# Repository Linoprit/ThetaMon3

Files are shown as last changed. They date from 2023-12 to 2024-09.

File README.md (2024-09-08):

# ThetaMon3

ThetaMon3 is based on an ESP32 controller, which reads a bunch of sensors and sends the results to a MQTT-Broker, like Mosquitto. I use three probes, together with my Home Assistant installation to control the temperature in remote buildings.

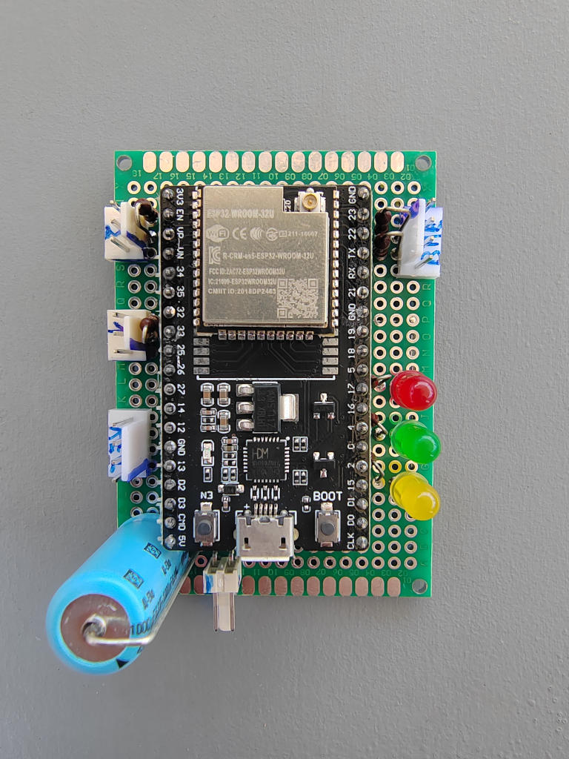
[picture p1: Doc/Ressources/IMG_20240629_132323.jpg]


## Features Overview

- Reads DS18B20 sensor array, connected to two channels. In the current configuration, it can read up to five sensors per channel. If you need more, simply increase DS18B20_MAX_DEVICES in Config.h.
- It also reads BME280 values, temp, hummidity and pressure.
- Currently, every channel needs at least one sensor. So a minimum configuration is two DS18B20 sensors and one BME280. 
- Based on a look-up table, placed as file image on the controller, two relays are switched, depending on the given thresholds. Every device works independently.
- Measurements are taken every minute and the average of these measurements are sent to an Mqtt broker every five minutes.
- There is a command-line-interface, you could connect to with a terminal programm, like GTK-Term. So you can have insight, what is going on in your setup and you can change several settings with it.
- Also, there are Mqtt-channels for remote accessing the device, or read loggings.

Why two OneWire-channels?<br>
I simply had the problem that in the workshop the location of the probe was in the middle of the sensor chain. Unfortunately, it was not possible to place it at one end or the other of the sensor chain.

## What's it all about? 

To understand what ThetaMon does and what it is meant for, we take a look at where the idea comes from.

My wife owns really a lot of pot-plants. These must be kept in a warmer place during the winter time, so we bring them into the garages. Unfortunately, on some days the outside temperatures could drop so low, that even in the garage the plants will die. Of course you use an electric heater, but the control of such devices is not particularly precise.
So the idea came up to build a system, that measures at different places in the room, to bring more insight how the heat is distributed and which places are save. Above that, to provide a finer regulation of the heating.

I put together the first version of ThetaMon, based on STM32F103 controllers, it consisted of two satellites and a base-station. The communication was done with NRF24 radios, which are long range capable (more or less...). The base-station was connected to an orange-pi which ran an apache webserver installation and hosted a page to show the graphs of all sensors for the last 24 hours. One very crucial point was, that the satellites work independently. If the connection to the base broke, they must have benn capable to do the regulation. This means, that every node in the system has to keep a table with all relevant temperature-thresholds.

This system ran fine for some years, but I wanted more flexibility and insight, if things went wrong. Sometimes temperature sensors failed, due to connector problems, or the NRF24 modules failed.
ThetaMon2 took a very long time to develop, and it became very complex. For example I needed an EEPROM with some kind of file-system to store the sensor tables. The html-generation was done by own code on the used Banana-Pi. Finaly it worked and it was used for one year.

In winter 2023 I took the time to try, if ESP32 with external antenna could keep a stable connection to the Wlan. And yes, it did! Also I looked for some different possibility to do the development and found, that PlatformIO is so much powerfull. Then, a colleague showed me what he does with home automation and I came up to use Home Assistant as dashboard solution.
ThetaMon3 took only a half year of development, not only because large parts of code from TM2 have been overtaken, it turned out that PlatformIO absolutely speeds up things.

## Getting started

Refer to: [SettingUpThetaMonProbe](https://github.com/Linoprit/ThetaMon3/blob/main/Doc/SettingUpThetaMonProbe.pdf).<br>
You need a working Visual Studio Code, together with PlatformIO. 

For a complete command-reference see [CommandLineReference](https://github.com/Linoprit/ThetaMon3/blob/main/Doc/CommandLineReference.pdf).

## Integrating to Home Assistant

The probes data is transmitted via mqtt, so you could integrate it whereever you want.
Because I use HA, I describe the integration for it. 

The name of your location (spot), where the probe is placed is defined in „MqttConfig.txt“, that resides on your ESP. Every sensor has a shortname, defined in „ID_Table_U64.txt“. These two names result in a mqtt publishing, in the form \<Location>/sens/\<Sensor-Shortname>. Your Home Automation system has to subscribe every sensor. The sensor data is transmitted in Json-format, i.e. "{"HUMID":51.21}"

Your Mosquitto installation and setup should have been done in the last step. You could use Home Assistants Mosquitto plugin.<br>
Go to the file /homeassistant/configuration.yaml, use the text-editor-plugin. 
Create a new section 
```
mqtt:
    sensor:
```
Then for every sensor enter a block like this:
```
    - name: "<Location> <Sensor-Shortname>"
      unique_id: <Location><Sensor-Shortname>
      state_class: "measurement"
      state_topic: "<Location>/sens/<Sensor-Shortname>"
      unit_of_measurement: "°C"
      expire_after: 480
      value_template: "{{ value_json.TEMP }}"
```
### Unit and value_template for other sensors:

Pressure:
```
      unit_of_measurement: "hPa"
      value_template: "{{ value_json.PRESS }}"
```

Hummidity:
```
      unit_of_measurement: "%"
      value_template: "{{ value_json.HUMID }}"
```

Relay:
```
      unit_of_measurement: "0/1"
      value_template: "{{ value_json.RELAY }}"
```

Example configuration:
```
# -- ESP32 Sensors --
mqtt:
    sensor:    
    - name: "Lager Temperatur"
      unique_id: LagerTmp
      state_class: "measurement"
      state_topic: "Lager/sens/LagerTmp"
      unit_of_measurement: "°C"
      expire_after: 480
      value_template: "{{ value_json.TEMP }}"
    - name: "Lager Luftdruck"
      unique_id: LagerPrs
      state_class: "measurement"
      state_topic: "Lager/sens/LagerPrs"
      unit_of_measurement: "hPa"
      expire_after: 480
      value_template: "{{ value_json.PRESS }}"
    - name: "Lager Luftfeuchte"
      unique_id: LagerHum
      state_topic: "Lager/sens/LagerHum"
      state_class: "measurement"
      unit_of_measurement: "%"
      expire_after: 480
      value_template: "{{ value_json.HUMID }}"
    - name: "Lager  Relay 1"
      unique_id: LagerRl1
      state_topic: "Lager/sens/LagerRl1"
      state_class: "measurement"
      unit_of_measurement: "0/1"
      expire_after: 480
      value_template: "{{ value_json.RELAY }}"
    - name: "Lager  Relay 2"
      unique_id: LagerRl2
      state_topic: "Lager/sens/LagerRl2"
      state_class: "measurement"
      unit_of_measurement: "0/1"
      expire_after: 480
      value_template: "{{ value_json.RELAY }}"
```

## Listen to the probes logging
Every probe publishes it's logging. It can be monitored with
```
mosquitto_sub -u mosquitto -P public -h <server-ip> -t <Location>/log
```

## Commands from remote
Via Mosquitto, commands can be sent to your probe with
```
mosquitto_pub -t '<Location>/cmd' -m '<Command>'
```
Best practise is to have a second terminal open with a running log-subscription.

## ToDo
- Explain how TM3 works. Measurement_Pivot, CommLine-Interface...?
- Discussion, if digital input / output channels are needed.
- Make Mqtt-credentials changeable, append them to MqttConfig.
- Move all Mqtt related commands in a structure and apply the "hasChanged" mechanism, used in sensor-configuration.

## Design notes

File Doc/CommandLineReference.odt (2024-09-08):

# ThetaMon3 Command-Line Reference

Refer to file “Interpreter.cpp”

Connect your computer to the ESP32 via USB-cable. Start a terminal-application like Gtk-Term, set the right port, i.e. /dev/ttyUSB0 or /dev/ttyACM0. Turn local echo off.

You could also use Visual Studio Codes Serial Monitor. Push the “Toggle Terminal Mode” button for enabling typing in commands.

Remember to shut down the terminal, or disconnect it, if you want to flash the ESP, or write the file-sytem image.

String arguments must be in double quotes (i.e. “Workshop”), Floats have to be written with a dot as decimal separator.

Like in Unix-terminals, you could access the history with arrow up / down.

setSensId <Sensor-Hash> <min> <max> <sensor-type> <relay-channel> “<shortname>”

float <min>:

Lower threshold, where the relay-channel is switched on.
float <max>:

Upper threshold, where the relay-channel is switched off,
int <sensor-type>:
0 – Temperature
1 – Humidity
2 – Pressure
3 – Relay (We treat Relays as sensor, to read their states)
int <relay-channel>:
0 – No channel. This sensor doesn’t switch anything.
1 – Channel 1.
2 – Obviously, Channel 2.
string “<shortname>”:
Name of the sensor. Because of history-reasons, it must be exactly eight
bytes long. I recommend to use underscores for padding, if your name is
shorter.

example:

setSensId 3822322055 10.0 12.5 0 1 "Test 007"

answer:

SensId ignored: 3822322055 (87:01:d4:e3:00:00:00:00)

** DONE **

calcHash <newCommand>

Calculates the hash value of the argument. Used only, if new commands will be implemented in code.

example:

calcHash blahdieblubb

answer:

Hash = 3496999634

getSensIdTable

Prints the content of the file „ID_Table_U64.txt“, that is stored in LittleFs filesystem.

example:

getSensIdTable

answer:

setSensId 288253003812035532 -12.5 -12.7 0 0 "WohnzTmp"

setSensId 360310597849963468 40.0 80.0 1 0 "WohnzHum"

setSensId 432368191887891404 846.0 1100.0 2 0 "WohnzPrs"

setSensId 720598568039603148 0.0 1.0 3 0 "WohnzRl1"

** DONE **

getStationId

Prints the base-address, used for sensor-id generation. It is the Mac-address of the device, added two zero bytes. Was used in ThetaMon2.

example:

getStationId

answer:

Station ID = 149609863437348 (24:dc:c3:c2:11:88:00:00)

printMeasures

One of the important commands. Prints the measurement of all connected sensors.

For every sensor a block, like following is reported:

sensId = 7638694032459628328 (28:ff:a6:40:c0:17:02:6a)

shortname = Test 005 sensType = TEMP

meanValue = 28.55 lastUpdateTick = 1213

valueIndex = 2 values = 28.50 28.50 28.69 28.56 28.50

minVal = -12.50 maxVal = -12.70

sensChan = CH_2 relayNr = 0

configChanged = false isTimeout = false

sensId: The address of the sensor as hash and 8-byte value

shortname: name of the sensor-address

sensType: type of the sensor

meanValue: The average of the internal array. Every minute a measuring is done,
every five minutes the meanValue is reported to the Mqtt-broker.

values: The internal values, from which meanValue is built.

minVal / maxVal: Thresholds, where relay is switched on/off.

sensChan: Internal. Shows to which channel the sensor is connected to.

relayNr: The relay, this sensor is bound to.

configChanged: Internal. Flags, if after booting the setting of the sensor was
changed. After saving the config (see saveSensIdTable), this flag is
cleared.

isTimeout: If there is no answer, longer than MEASUREMENT_TIMEOUT_SEC (Config.h)
the sensor is flagged timeout and is no more reported to the broker.

listDir

Shows the contents of LittleFs. Usually there should only be two files,

ID_Table_U64.txt and MqttConfig.txt.

example:

listDir

answer:

Listing directory: /

FILE: ID_Table_U64.txt SIZE: 2264

FILE: MqttConfig.txt SIZE: 134

readFile “<filename>”

Prints the contents of a file. The filename must be preceded by “/”!

example:

readFile "/MqttConfig.txt"

answer:

setMqttHost 192 198 153 122

setMqttPort 1883

setMqttSpot "Testboard"

startWifi "My-SSID" "08151234567Passkey"

saveSensIdTable

Saves any changes, made to the sensor-config to the LittleFs file-system.

(At time of writing this, the command fails and the device reboots, if no changes are made to the sensor-table before.)

example:

saveSensIdTable

answer:

** DONE **

getMacAddress

Prints the Mac-Address of your device.

example:

getMacAddress

answer:

DEC 36:220:195:194:17:136 (HEX 24:dc:c3:c2:11:88)

** DONE **

setMqttHost <Ip-Address_of_your_Mqtt-broker>

Set the Mqtt-Server address. Must be written with blanks, instead of dots between the numbers. Setting will not be stored

example:

setMqttHost 192 158 234 136

answer:

** DONE **

setMqttPort <Port>

int <Port>: Mqtt-Server-port. Usually 1883. Setting will not be stored.

example:

setMqttPort 1883

answer:

** DONE **

startWifi "<SSID>" "<PASS>"

Fires up the Wifi with given credentials. Setting will not be stored.

example:

startWifi "someSSID" "somePass"

stopWifi

Shuts the Wifi down.

setMqttSpot <Location>

string <Location>: Sets the name of the location. This name is used in the Mqtt-publishing. Setting will not be stored.

example:

setMqttSpot "someLocation"

answer:

** DONE **

getMqttConf

Prints the current Mqtt-Setup.

example:

getMqttConf

answer:

WIFI is connected, local IP: 192.168.178.98

MqttHost: 192.238.142.127:1883

Mqtt publish sensordata: 'someLocation/sens'

Mqtt publish logs: 'someLocation/log'

Mqtt subscribe commands: 'someLocation/cmd'

** DONE **

storeWifi "<SSID>" "<PASS>"

Stores the given Wifi settings, to “MqttConfig.txt”. The file will be appended with a startWifi command.

storeMqttSpot “<Location>”

string <Location>: Appends “MqttConfig.txt” with a setMqttSpot command.

storeMqttHost <Host-Ip>

int int int int Host-Ip: Appends “MqttConfig.txt” with setMqttHost command. Remember to uses blanks, instead of dots.

storeMqttPort <Port>

int <Port>: Same with setMqttPort.

tstRelay <Relay-Nr> <State>

Switches the corresponding relay on or off. A test-timer is started, currently 2 min, that preserves the state of the relay beeing changed from a sensor reaching a threshold. After the timer is expired, the relay is automatically switched off. If any sensor is within its thresholds, the relay will be switched in the next cycle.

int <Relay-Nr>: 1 or 2, no other values allowed.

int <State>: 0 or 1, no other values allowed.

example:

tstRelay 1 1

answer:

** DONE **

cycle

A cycle is done every minute. In a cycle all sensors are read and the relay-states are calculated. In test or setup situations, you don't necessarily want to wait that long. This command triggers cycling.

After hitting enter, the ESP seems to be frozen for a second or two. Don’t be nervous, just wait.

After five cycles the mqtt reporting is done.

example:

cycle

answer:

** DONE **

shutup

This command inhibits any output to the terminal. It is useful, when you run some scripts on your computer, that push messages right into the serial.

example:

shutup

answer:

(nothing happens)

talk

Enables the terminal outputs again.

example:

talk

answer:

Serial print is active.

** DONE **

reboot

Reboots the device.

exit

On ESP devices, it does the same as reboot.

clear

Clears the screen.

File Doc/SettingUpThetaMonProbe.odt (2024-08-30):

Setting up the ThetaMon-Probe

We use Visual-Studio Code together with the PlattformIo Plugin.

1. Clone the project and open the directory „ThetaMon3/Probes/ThetaProbe/“ in VSC. Build the firmware and flash it to the ESP32 board.
2. Prepare a file, named „MqttConfig.txt“ and place it in the „data“ directory. The content should be following:  setMqttHost 192 201 273 83 <-- Your Mqtt broker IP (use spaces instead of dots!) setMqttPort 1883 <-- Your Mqtt broker Port setMqttSpot "LivingRoom" <-- Name of the place, where the probe is placed startWifi "<Your-SSID>" "<Your-SSID-Passphrase>"  The IP-Address must be given with blanks, instead of dots. The Mqtt-Spot-Name, is used to connect to HomeAssistant, or alike. The SSID and SSID-Passphrase have to be double-quoted.
3. In Visual Studio Code, go to PlattformIO, then „Build Filesystem Image“, then „Upload Filesystem Image“

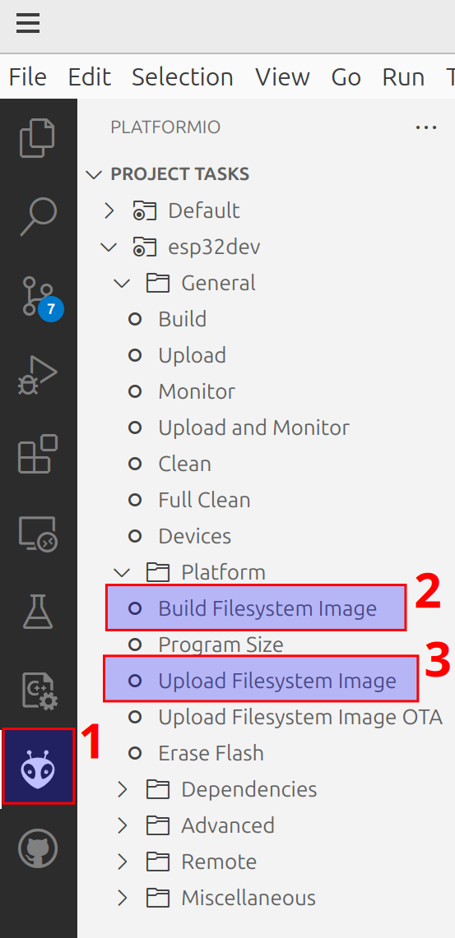
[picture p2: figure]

4. Open a Terminal program, like GTK-Term, connect to the ESP32-console, press Enter and you should see a command prompt.

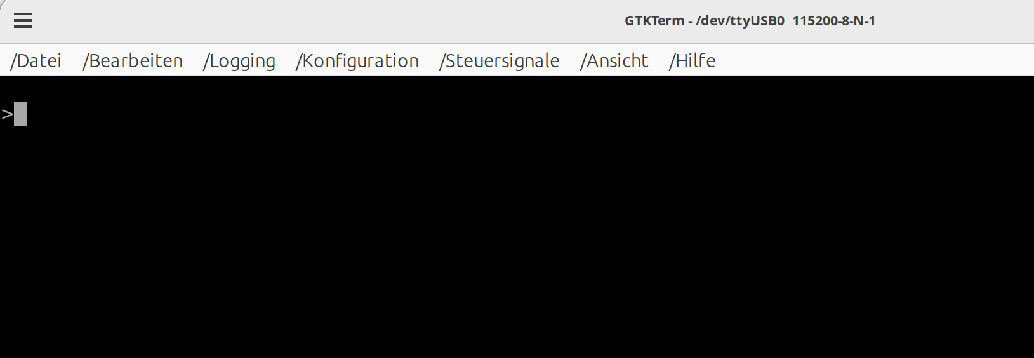
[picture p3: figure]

5. Type „printMeasures“, you should see data of the connected sensors.  The BME280 Sensor has three entries for Hummidity, Air-Pressure and Temperature. Your printing may look different, because the sensor-Ids are not yet registered in “ID_Table_U64.txt”. The first six segments of the Id are the Mac-Address of your ESP device. You could get the Mac-Address of your device, simply by typing „getMacAddress“ into the console:

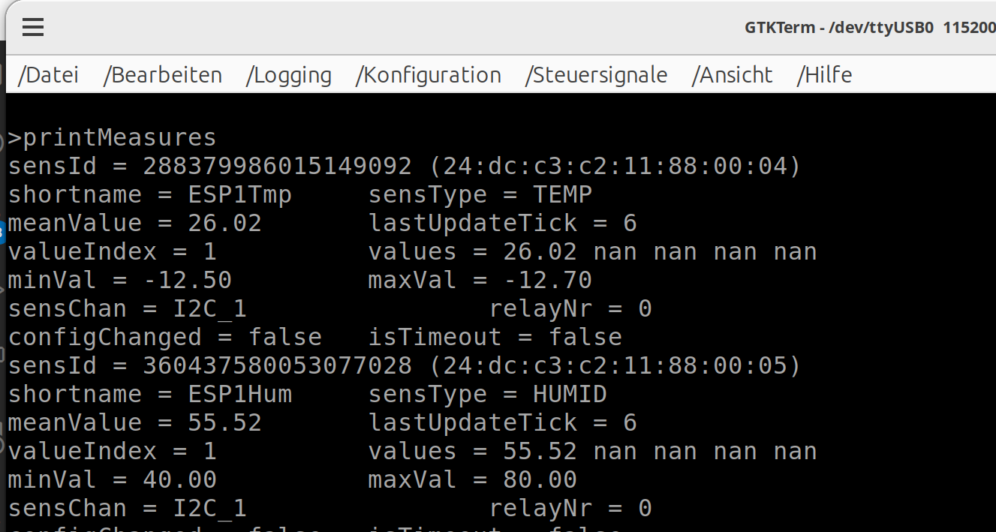
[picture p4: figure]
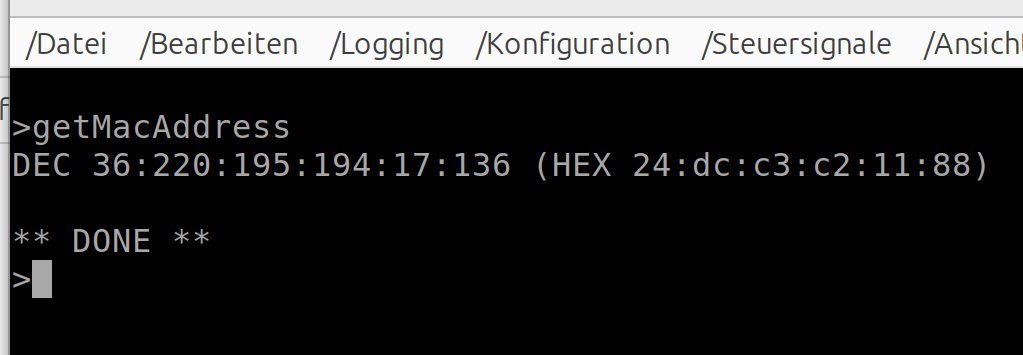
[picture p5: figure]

6. Open „ID_Table_U64.txt“ in the data-directory. You see a collection of commands, that set up the sensor configuration. Every line can also be typed into the console. Example line:  setSensId 288253003812035532 -12.5 -12.7 0 0 "WohnzTmp"  „setSensId“ is the command to define sensor attributes, followed by a hash-value of the sensor-address (more to this below).  -12.5: the lower threshold, where the relay-channel is switched on.  -12.7: the upper threshold, where the relay-channel is switched off,  0: (the first one) is the sensor-type. 0 – Temperature 1 – Humidity 2 – Pressure 3 – Relay (We treat Relays as sensor, to read their states)  0: (the second one) defines the relay-channel, that this sensor is bound to. 0 – No channel. This sensor doesn’t switch anything. 1 – Channel 1. 2 – Obviously, Channel 2.  Refer to the schematic, connector J2 to see, how to connect the corresponding relay-channels are to be connected. I use two-channel Arduino rely-boards.  "WohnzTmp": is the short Name of the sensor. It must be exactly eight characters long. This name is used together with the location-name in „MqttConfig.txt“ to build the Mqtt publishing name, in example “Testboard/sens/WohnzTmp” (note the ‚sens‘ in the middle!). If you have mosquitto installed at your machine, the following command shows the message updating the sensor data  > mosquitto_sub -u mosquitto -P public -h 192.168.178.103 -t 'Testboard/sens/Test 005'  Please note, that this message is sent only every five minutes.

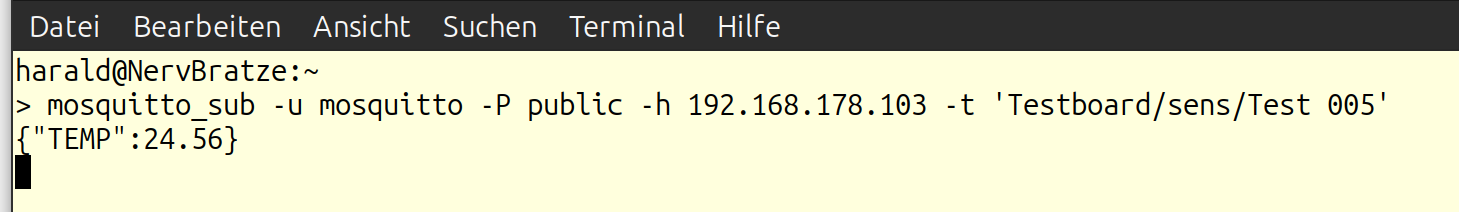
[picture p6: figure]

7. If you now type „printMeasures“ again, you will be shown the actual setting. Bring the hashes into your Id-Table-file, give every sensor a shortname and if you need it define the switching thresholds and the relay-binding.  To get out, which sensor belongs to which address, simply warm them up with your hands and print the measures again. Never ever use a lighter, this will destroy the sensor!
8. Save this file into the data directory, build the file-system again and upload it. Reboot your ESP. Remember to close your terminal-connection before connecting with Visual Studio.
9. Go back to your console-connection. Check that every sensor is recognized. Type „reboot“ and watch the output. If a sensor was set up correct, you get something like:  >setSensId 4179915027513875496 -12.5 -12.7 0 0 "INNEN_O2" UpdateConfig done.  ** DONE **  otherwise:  >setSensId 14484146576875228968 -12.5 -12.7 0 0 "Test 012" SensId ignored: 14484146576875228968 (28:8f:56:45:92:06:02:c9)  ** DONE **
  Of course you could set all of your sensors into a single file and download it to all of your probes. Not connected sensors will simply be ignored.
10. If everything went well, you are done. The probe will send the actual values every five minutes to your mqtt-broker.  There are some python tools, you could have a look at.

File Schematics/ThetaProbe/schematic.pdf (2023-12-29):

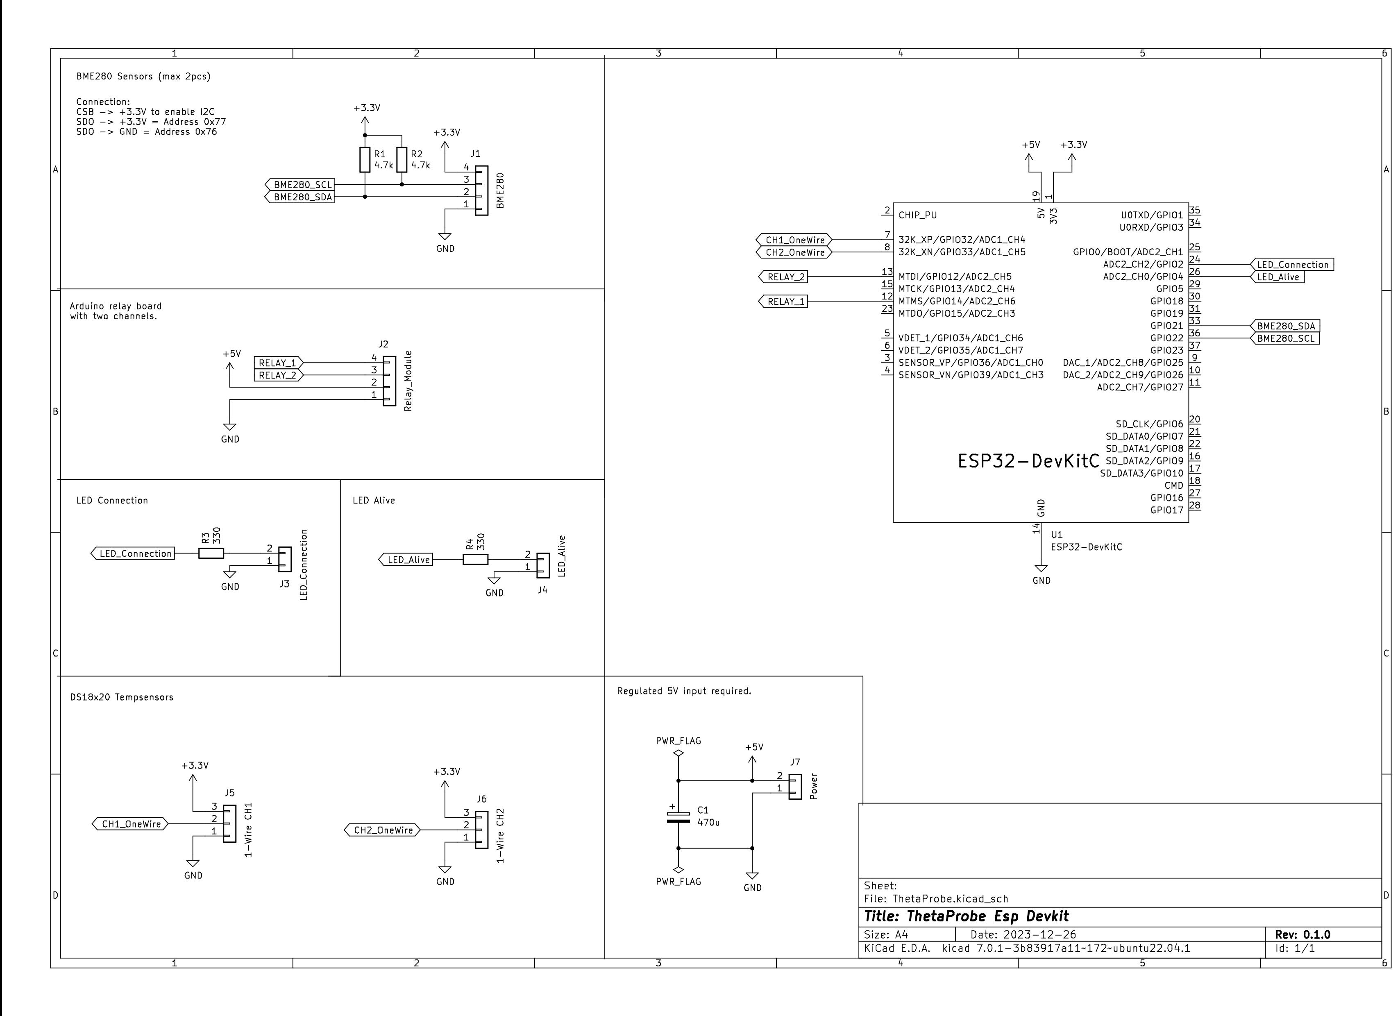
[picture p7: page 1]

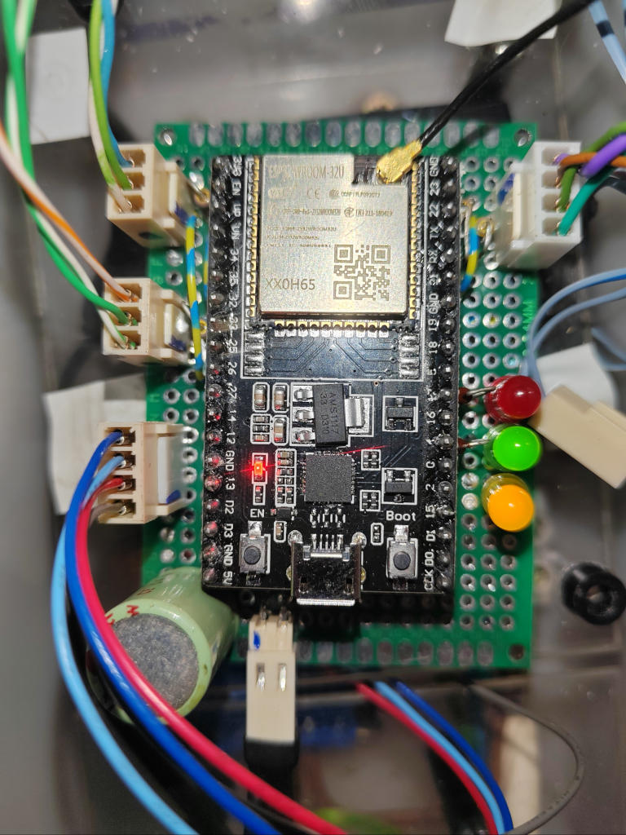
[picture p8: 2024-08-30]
Doc/Ressources/IMG_20240623_202413_edit_32841651561116.jpg

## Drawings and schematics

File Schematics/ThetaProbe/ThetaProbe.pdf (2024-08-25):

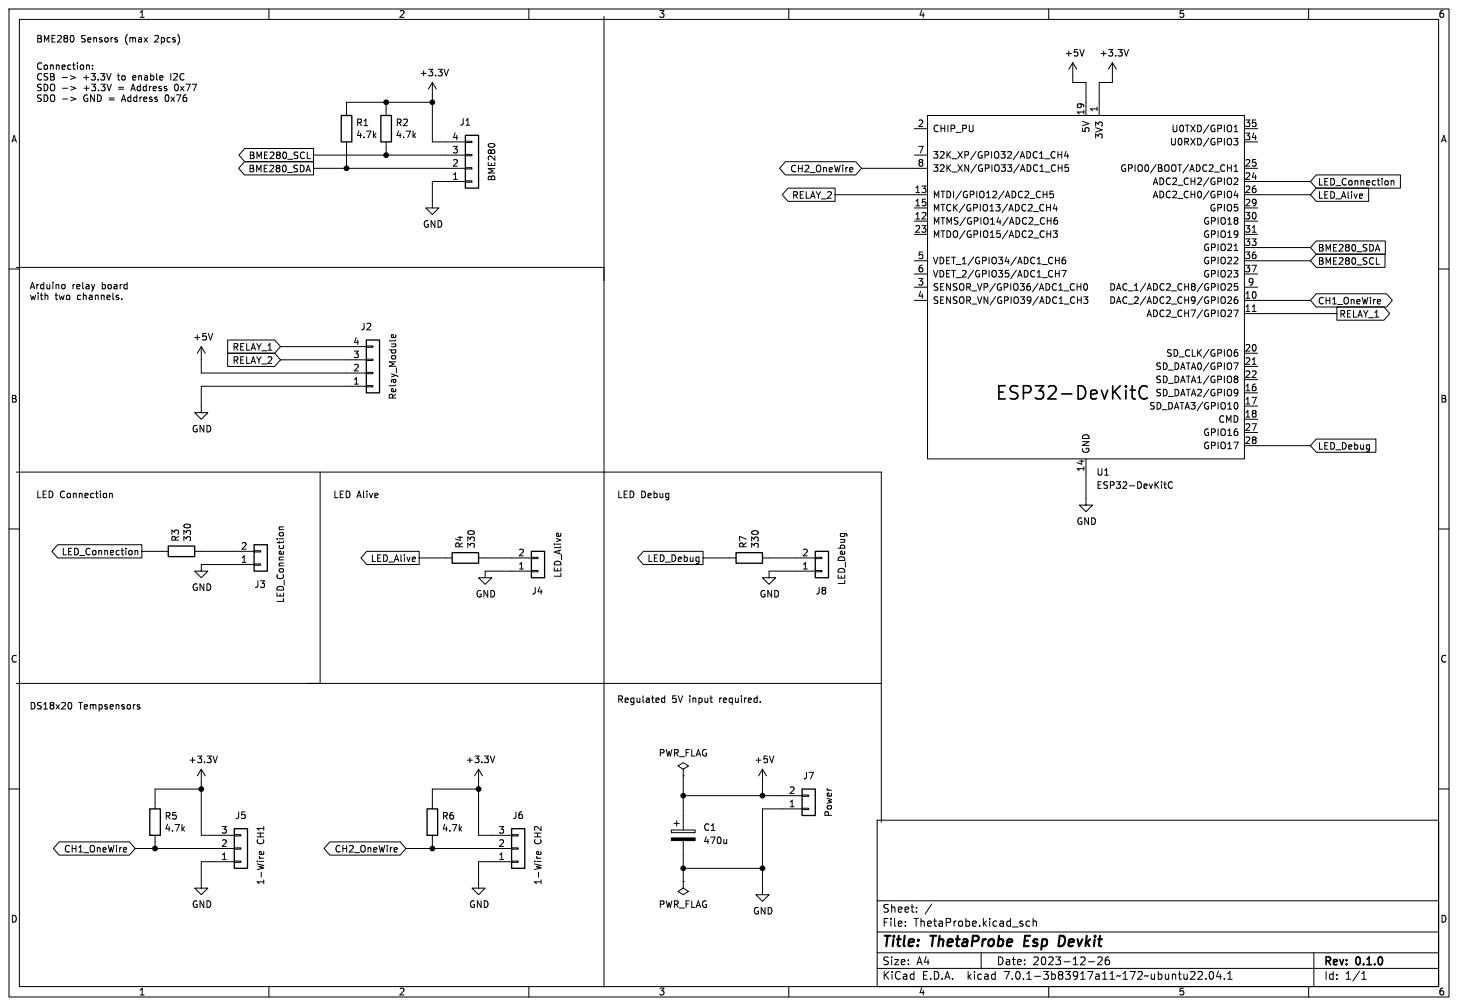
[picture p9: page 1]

1 DAC_2/ADC2_CH9/GPIO26 10 ADC2_CH7/GPIO27 11 MTMS/GPIO14/ADC2_CH6 12 MTDI/GPIO12/ADC2_CH5 13 MTCK/GPIO13/ADC2_CH4 15 SD_DATA2/GPIO9 16 SD_DATA3/GPIO10 17 CMD 18 CHIP_PU 2 SD_CLK/GPIO6 20 SD_DATA0/GPIO7 21 SD_DATA1/GPIO8 22 MTDO/GPIO15/ADC2_CH3 23 ADC2_CH2/GPIO2 24 GPIO0/BOOT/ADC2_CH1 25 ADC2_CH0/GPIO4 26 GPIO16 27 GPIO17 28 GPIO5 29 SENSOR_VP/GPIO36/ADC1_CH0 3 GPIO18 30 GPIO19 31 GPIO21 33 U0RXD/GPIO3 34 U0TXD/GPIO1 35 GPIO22 36 GPIO23 37 SENSOR_VN/GPIO39/ADC1_CH3 4 VDET_1/GPIO34/ADC1_CH6 5 VDET_2/GPIO35/ADC1_CH7 6

Id: 1/1 Title: ThetaProbe Esp Devkit File: ThetaProbe.kicad_sch Sheet: / R3 330
J3 LED_Connection

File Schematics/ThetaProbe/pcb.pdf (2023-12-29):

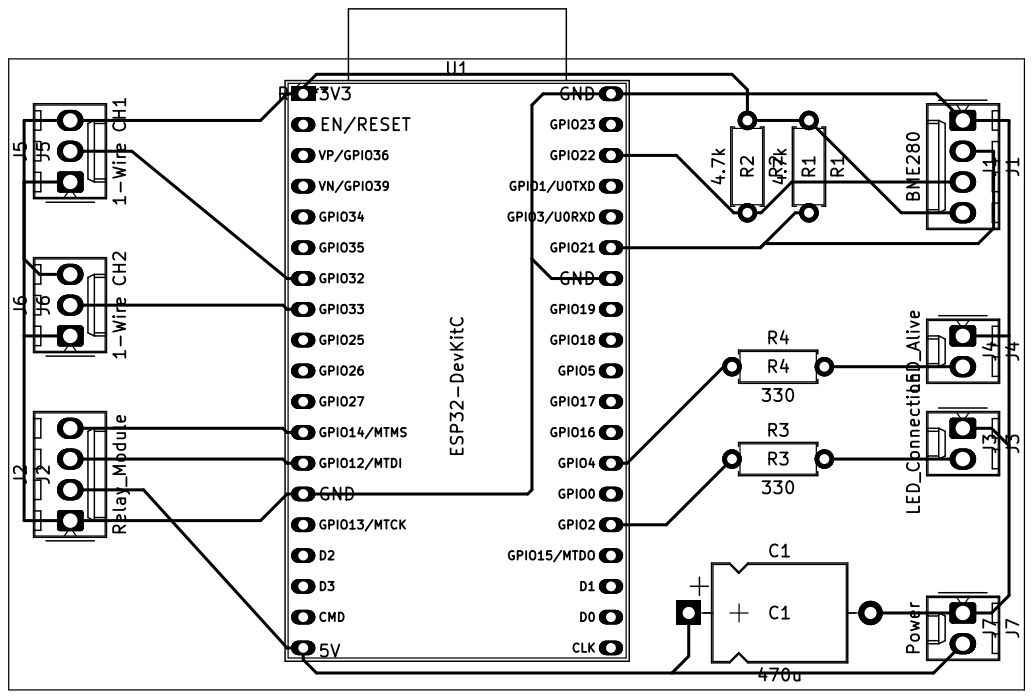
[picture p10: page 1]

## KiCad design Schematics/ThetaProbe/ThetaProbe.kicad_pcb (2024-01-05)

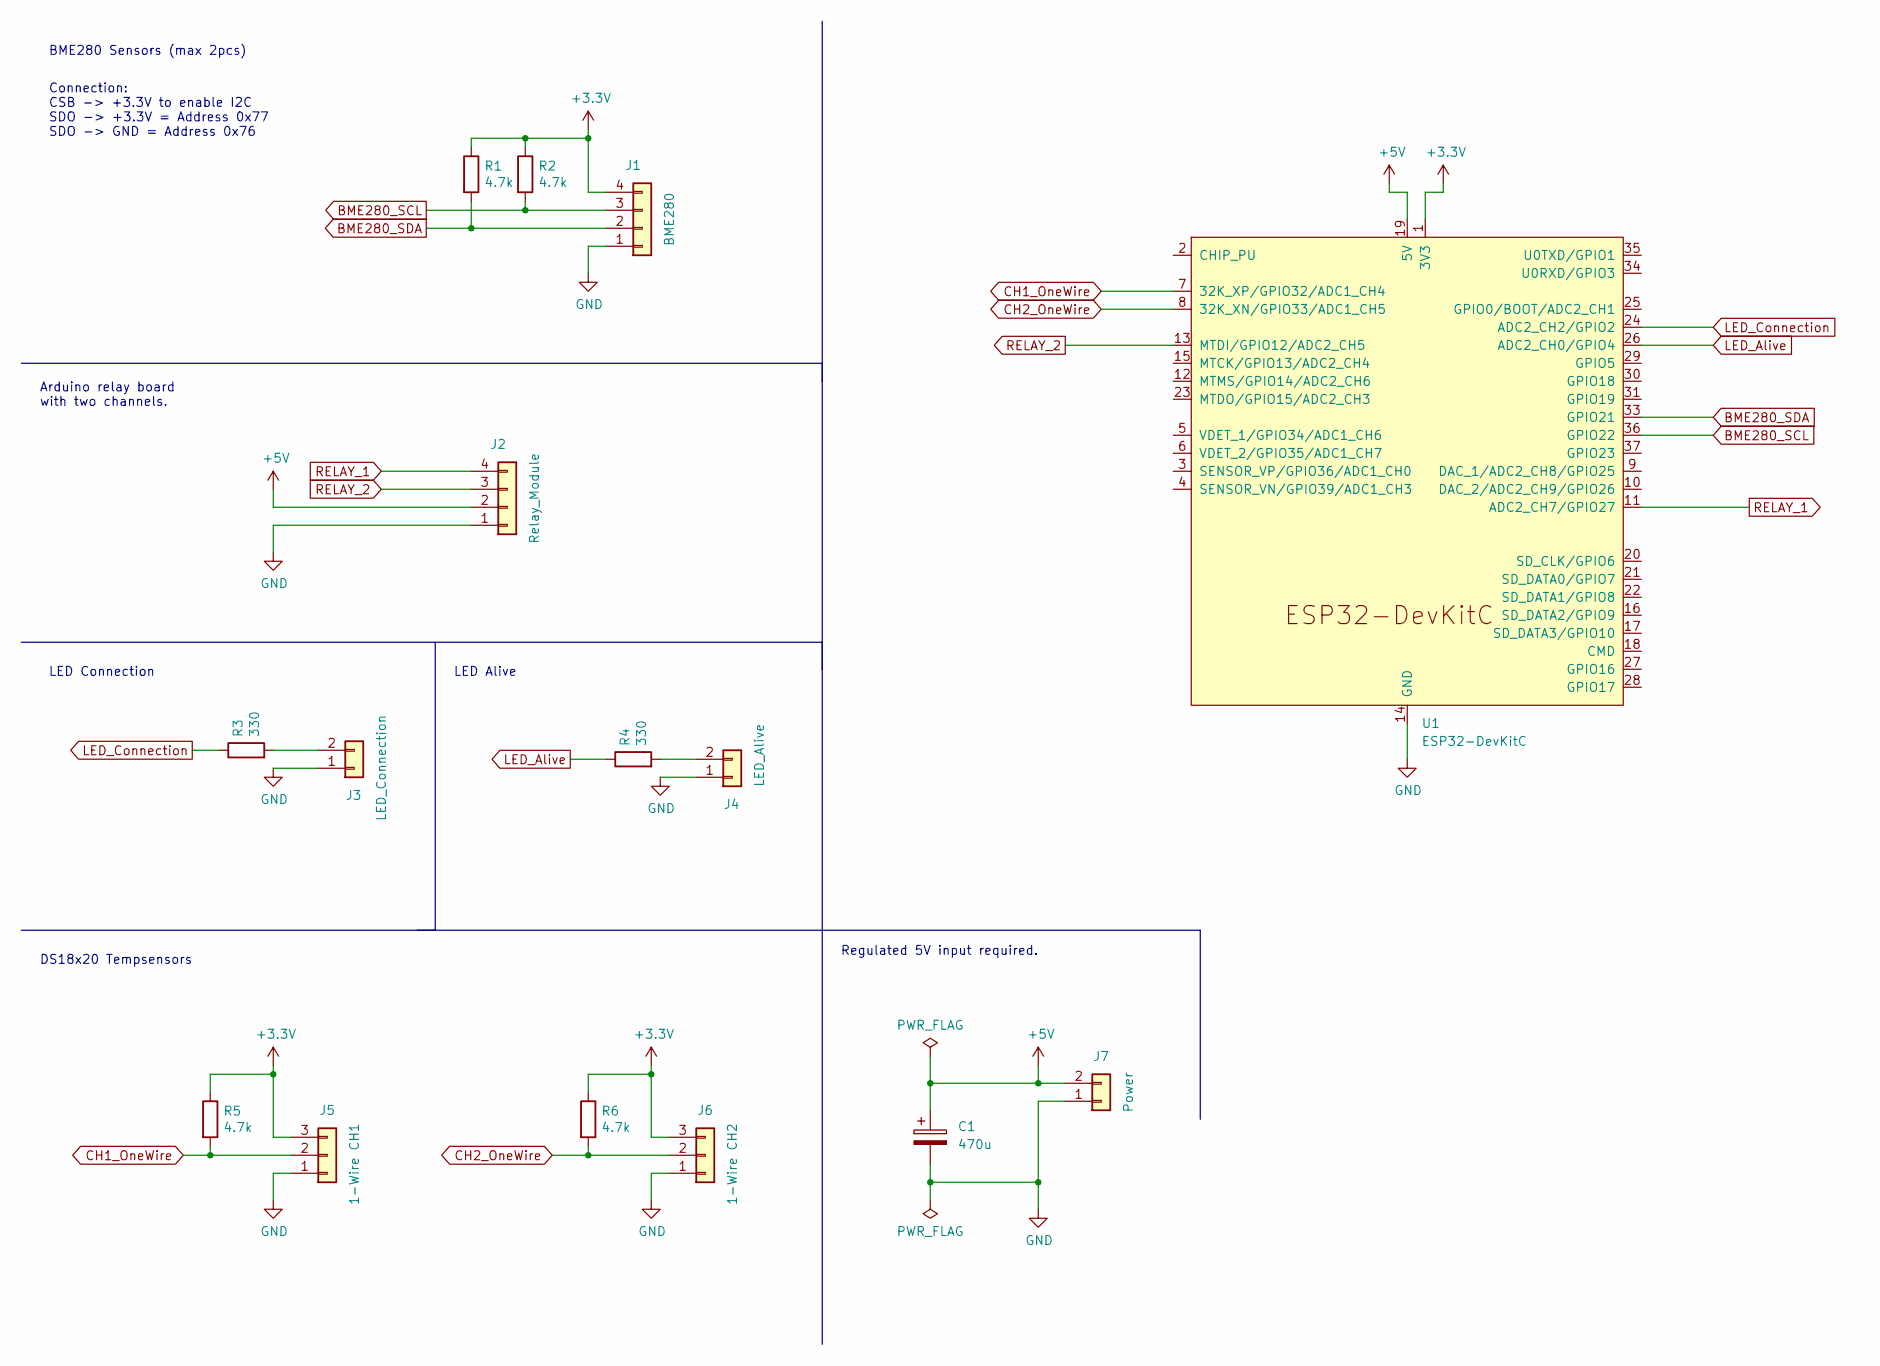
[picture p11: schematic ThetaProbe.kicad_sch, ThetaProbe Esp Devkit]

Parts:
C1: 470u; CP_Axial_L11.0mm_D8.0mm_P15.00mm_Horizontal
J1: BME280; Molex_KK-254_AE-6410-04A_1x04_P2.54mm_Vertical
J2: Relay_Module; Molex_KK-254_AE-6410-04A_1x04_P2.54mm_Vertical
J3: LED_Connection; Molex_KK-254_AE-6410-02A_1x02_P2.54mm_Vertical
J4: LED_Alive; Molex_KK-254_AE-6410-02A_1x02_P2.54mm_Vertical
J5: 1-Wire CH1; Molex_KK-254_AE-6410-03A_1x03_P2.54mm_Vertical
J6: 1-Wire CH2; Molex_KK-254_AE-6410-03A_1x03_P2.54mm_Vertical
J7: Power; Molex_KK-254_AE-6410-02A_1x02_P2.54mm_Vertical
R1, R2, R5, R6: 4.7k; R_Axial_DIN0207_L6.3mm_D2.5mm_P7.62mm_Horizontal
R3, R4: 330; R_Axial_DIN0207_L6.3mm_D2.5mm_P7.62mm_Horizontal
U1: ESP32-DevKitC

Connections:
+3V3: J1.4, J5.3, J6.3, R1.1, R2.1, R5.1, R6.1, U1.1 (3V3)
+5V: C1.1, J2.2, J7.2, U1.19 (5V)
BME280_SCL: J1.3, R2.2, U1.36 (GPIO22)
BME280_SDA: J1.2, R1.2, U1.33 (GPIO21)
CH1_OneWire: J5.2, R5.2, U1.7 (32K_XP/GPIO32/ADC1_CH4)
CH2_OneWire: J6.2, R6.2, U1.8 (32K_XN/GPIO33/ADC1_CH5)
GND: C1.2, J1.1, J2.1, J3.1, J4.1, J5.1, J6.1, J7.1, U1.14 (GND), U1.32 (GND), U1.38 (GND)
LED_Alive: R4.1, U1.26 (ADC2_CH0/GPIO4)
LED_Connection: R3.1, U1.24 (ADC2_CH2/GPIO2)
unnamed: J3.2, R3.2
unnamed: J4.2, R4.2
RELAY_1: J2.4, U1.11 (ADC2_CH7/GPIO27)
RELAY_2: J2.3, U1.13 (MTDI/GPIO12/ADC2_CH5)

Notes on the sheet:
BME280 Sensors (max 2pcs)
DS18x20 Tempsensors
Connection: CSB -> +3.3V to enable I2C SDO -> +3.3V = Address 0x77 SDO -> GND = Address 0x76
LED Alive
LED Connection
Arduino relay board with two channels.
Regulated 5V input required.

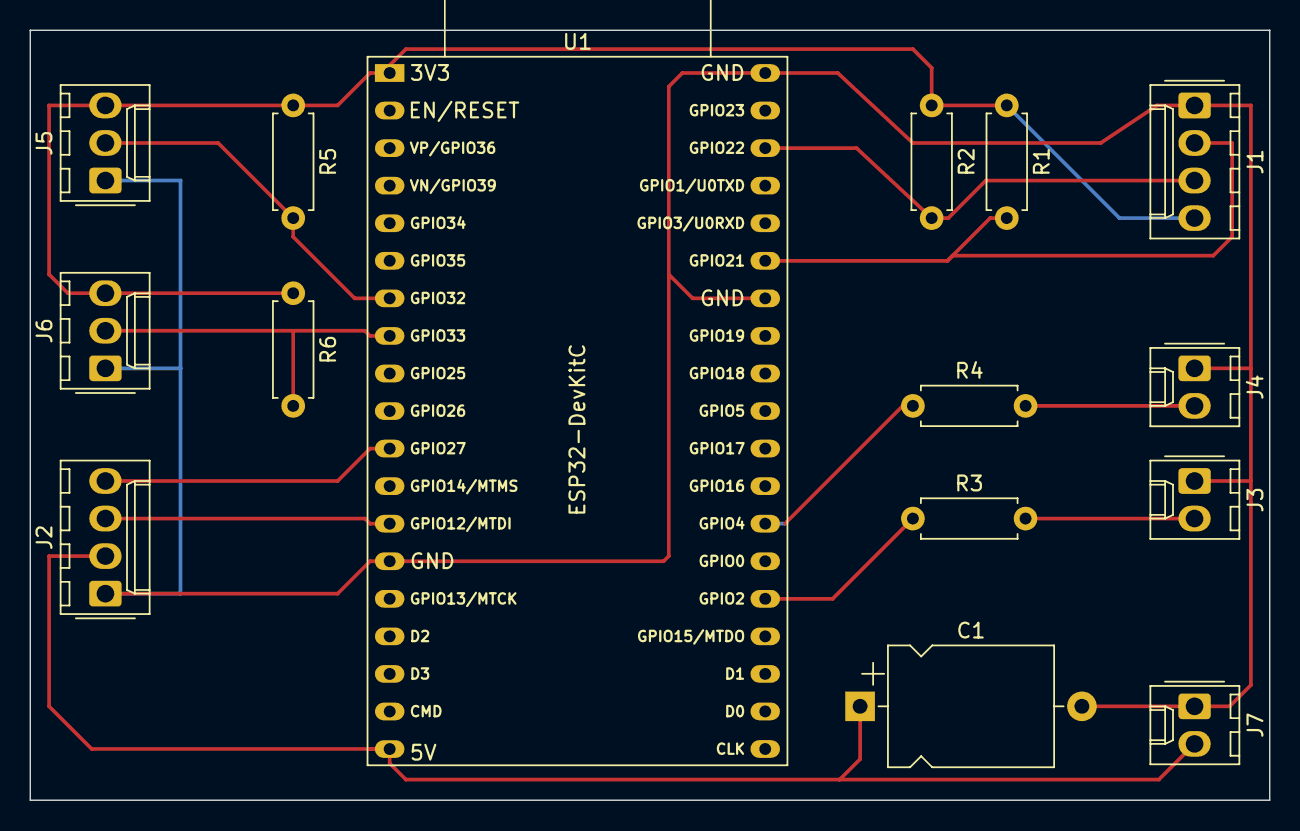
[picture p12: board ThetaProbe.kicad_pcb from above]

Board: 2 copper layers, 83.8 x 52.1 mm, 15 parts (0 on the bottom side), 13 nets.

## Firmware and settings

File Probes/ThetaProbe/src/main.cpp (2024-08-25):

#include "Config.h"
#include "TasksCommon.h"
#include <Arduino.h>
#include <DigitalIo/GpioInOut.h>
#include <FileSystem/LittleFsHelpers.h>
#include <OsHelpers.h>
#include <Sensors/Measurement.h>
#include <Sensors/MeasurementPivot.h>
#include <Wifi/MqLog.h>
#include <Wifi/MqttHelper.h>

// Common tasks and queues definition
TaskHandle_t sensorTaskHandle = NULL;
TaskHandle_t comLineTaskHandle = NULL;

void setup() {
  Serial.begin(115200);
  Serial.println();

  xTaskCreate(startComLineTask, "ComLineTask", 3024, NULL, 1,
              &comLineTaskHandle);
  delay(500);

  gpio::GpioInOut::instance().init();
  gpio::GpioInOut::instance().initHardware();

  nvm::LittleFsHelpers::instance().init();
  nvm::LittleFsHelpers::instance().initHardware();

  // Init sensor task. The sensor init also inits Wifi and Mqtt
  // Because we push commands to the interpreter-queue, this must happen
  // in sequence.
  xTaskCreate(startSensorsTask, "SENSOR_TASK", 3024, NULL, 1,
              &sensorTaskHandle);
}

void loop() {
  static uint_fast8_t aliveLedCycleCount = 0;

  MqLogCycle();

  aliveLedCycleCount++;
  if (aliveLedCycleCount > 100) {
    aliveLedCycleCount = 0;
    gpio::GpioInOut::instance().tglLedAlive();    
  }

  delay(10);
}

////// BEGIN Code for testing
// #include "DallasTemperature.h"
// #include <Config.h>
// #include <OneWire.h>
// #include <OneWire_direct_gpio.h>
// #include <Sensors/Measurement.h>

// using namespace msmnt;
// using namespace std;

// OneWire oneWireCh1;
// OneWire oneWireCh2;
// DallasTemperature* _sensorsCh;

// void setup() {
//   Serial.begin(115200);
//   oneWireCh1.begin(ONE_WIRE_CH1_PIN_OUT, ONE_WIRE_CH1_PIN_IN);
//   oneWireCh2.begin(ONE_WIRE_CH2_PIN_OUT, ONE_WIRE_CH2_PIN_IN);
//   _sensorsCh = new DallasTemperature(&oneWireCh1);
//   _sensorsCh->setResolution(12);
//   //pinMode(18, OUTPUT);
// }

// void loop() {

//   // directWriteLow(ONE_WIRE_CH1_PIN_OUT);
//   // delayMicroseconds(65);
//   // directWriteHigh(ONE_WIRE_CH1_PIN_OUT);

//   // directWriteLow(ONE_WIRE_CH2_PIN_OUT);
//   // delayMicroseconds(65);
//   // directWriteHigh(ONE_WIRE_CH2_PIN_OUT);

//   // bool pPulse = oneWireCh1.reset();
//   // if (pPulse) {
//   //   Serial.printf("Got pPulse.\n");
//   // } else {
//   //   Serial.printf("No pPulse.\n");
//   // }

//   // DeviceAddress address;
//   // oneWireCh1.reset_search();

//   // while (oneWireCh1.search(address)) {
//   //   std::string id = msmnt::Measurement::DumpSensIdArray(address);
//   //   Serial.printf("found: %s\n", id.c_str());

//   //   if (OneWire::crc8(address, 7) != address[7]) {
//   //     MqLog("CRC is not valid!\n");
//   //     continue;
//   //   }
//   // }


//   uint8_t address[8];
//   uint8_t senorCount = 0;
//   _sensorsCh->begin();
//   oneWireCh1.reset_search();

//   // MqLog("Searching oneWire on channel %s\n",
//   //       Measurement::DumpSensChannel(_channel).c_str());

//   while (oneWireCh1.search(address)) {
//     Serial.printf("ROM = %s\n", Measurement::DumpSensIdArray(address).c_str());

//     if (OneWire::crc8(address, 7) != address[7]) {
//       Serial.printf("CRC is not valid!\n");
//       continue;
//     }
//     //_measurementPivot->StoreSensId(address, _channel);
//     senorCount++;
//   }
//   Serial.printf("Found sensors: %i\n", senorCount);

//   delay(500);
// }

////// END Code for testing

/*
mosquitto_sub -h localhost -t Lager/sens
mosquitto_sub -h localhost -t Lager/log
mosquitto_sub -u <user> -P <pass> -h 192.168.178.103 -t Lager/log
mosquitto_pub -t 'Lager/cmd' -m 'printMeasures'

ssh -v harald@192.168.178.108
*/

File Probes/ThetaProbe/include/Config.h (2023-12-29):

#ifndef INSTANCES_CONFIG_H_
#define INSTANCES_CONFIG_H_

#include <stdint.h>

// ******* One Wire *******
constexpr uint8_t ONE_WIRE_CH1_PIN = 32;
constexpr uint8_t ONE_WIRE_CH2_PIN = 33;

// ******* DS18B20 device *******
// Conversion precision in bit
constexpr uint8_t DS18B20_PRECISION = 12;

constexpr uint8_t DS18B20_SEARCH_RETRIES = 6;
constexpr uint8_t DS18B20_MAX_DEVICES = 4; // in one channel

// [ms] doAllMeasure(): how long to wait until all devices finished conversion
// If this time is passed, sensor-value is set to NAN
constexpr uint32_t DS18B20_CONVERSION_TIMEOUT_MS = 5000;

// time in [ms], the measureTask delays
constexpr uint32_t MEASURETASK_CYCLE = 5000;

// how many sensors can be present on a device. Should be the same in the whole network.
// (DS1820 Sensors * Channels + BME280 Temp/Humi/Press + RelayStates)
constexpr uint8_t MAX_SENSORS = (DS18B20_MAX_DEVICES * 2 + 3 + 1);

// ******* BME280 *******
//constexpr uint8_t BME280_I2CADDR = 0xEC		// 0x76<<1	SDO -> GND
constexpr uint8_t BME280_I2CADDR = 0xEE;		// 0x77<<1	SDO -> VCC
constexpr uint8_t BME280_SDA_PIN = 21;
constexpr uint8_t BME280_SCL_PIN = 22;
// float getSealevelForAltitude() 
//    const {return (float) _bme280_data.pressure / 100.0 / pow(1.0 - (_altitude / 44330.0), 5.255);}

#endif /* INSTANCES_CONFIG_H_ */

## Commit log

2024-01-05 MeasurementPivot with tests done.
    [ThetaProbe.kicad_pcb, ThetaProbe.kicad_sch]
2024-01-21 Old TableIdTool recycled.
    [ID_Table.csv]
2024-02-11 Mqtt publishing of sensor data done
2024-02-15 GPIO Leds and Relays working
2024-03-17 starting with transfering onewire from old stm32 version.
2024-03-29 Final version with 5V push-pull schematic.
    Still problems with reading out some sensors. It's no timing issue, and
    no electrical issue. Sensors broken?
    [main.cpp]
2024-03-29 Switching to 3.3V OneWire
2024-04-05 Debug LED added.
    [ThetaProbe.kicad_sch]
2024-08-30 Begun documentation
    [ID_Table.csv]
